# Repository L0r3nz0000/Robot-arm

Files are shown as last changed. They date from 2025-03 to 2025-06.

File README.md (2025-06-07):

# 🤖 Braccio Robotico con Arduino

## 🔧 Introduzione

Questo progetto nasce da un’idea personale, realizzato interamente in autonomia con l’obiettivo di costruire un **braccio robotico a 3 gradi di libertà** utilizzando **stampa 3D** e componenti elettronici a bassissimo costo. Il sistema è pensato per essere controllato in **tempo reale** tramite diverse interfacce.

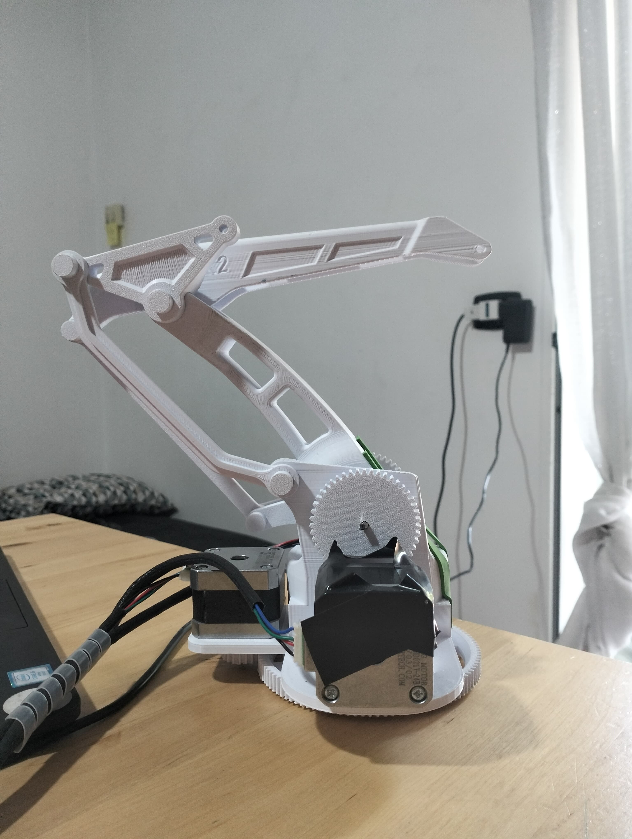
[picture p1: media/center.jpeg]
Braccio Robotico


---

## 🛠️ Struttura Meccanica

- **Gradi di libertà:** 3
- **Base:** rotazione completa a 360° sull'asse verticale  
- **Primo snodo:** movimento fino a 180°  
- **Secondo snodo:** movimento angolare variabile, condizionato dall’orientamento del braccio

**Materiale:** PLA (Polylactic Acid), stampato in 3D  
**Modelli CAD:** scaricati da [Thingiverse](https://www.thingiverse.com/)  
**Trasmissione del moto:** giunti con ingranaggi e riduttori meccanici per aumentare la coppia disponibile

---

## ⚙️ Componenti Elettronici

- **Microcontrollore:** Arduino Uno €20
- **Motori:** 3 × motori stepper NEMA17 €15 - €30
- **Driver motori:** 3 × DRV8825 €3
- **Scheda di controllo:** CNC Shield V3 per Arduino €5
- **Buzzer:** Buzzer passivo elegoo €1.5
- **Alimentazione:** 12V tramite alimentatore esterno

### Totale: ~ €50

---

## 🖥️ Sistema di Controllo e Software

Il braccio è controllabile in **tempo reale** attraverso due modalità principali:

### 1. 🕹️ Controller PlayStation 5

- Acquisizione degli input tramite `pygame`
- Invio comandi seriali diretti ad Arduino

### 2. 🌐 Interfaccia Web (Flask)

- Applicazione web in Python con `Flask`
- Controllo del braccio tramite browser locale

### Architettura Software

**Firmware Arduino**
- Linguaggio: C++
- Nessuna libreria esterna utilizzata

**Client PC**
- Linguaggio: Python
- Librerie principali: `serial` (comunicazione), `pygame` (input controller)

---

## 🧪 Test e Risultati

✅ Il braccio risponde ai comandi con **latenza minima** e **movimenti fluidi**  
✅ La precisione dei motori è molto alta, grazie ai driver che permettono microstep di 1/32 di step e per fare un giro completo dobbiamo fare 64 step, 64*32 = 2048 step per fare un giro completo, quindi otteniamo un'accuratezza di ~0.176 gradi

### Limiti attuali:

- ❌ Assenza di feedback di posizione (encoder/potenziometri)
- ❌ Vincoli meccanici sul terzo snodo per geometria attuale
- ❌ Nessun finecorsa → minor affidabilità in sessioni lunghe

---

## 🚀 Espansioni Future

- ✅ Installazione di finecorsa o sensori di posizione  
- ✅ Aggiunta di ulteriori gradi di libertà (es. **pinza terminale**)  
- ✅ Integrazione di un modulo wireless che permetta di lavorare in modo autonomo (ESP32 o modulo Bluetooth 5.0)  
- ✅ Modalità autonoma programmabile (tramite cinematica inversa)
---

### 📷 Scheda di controllo
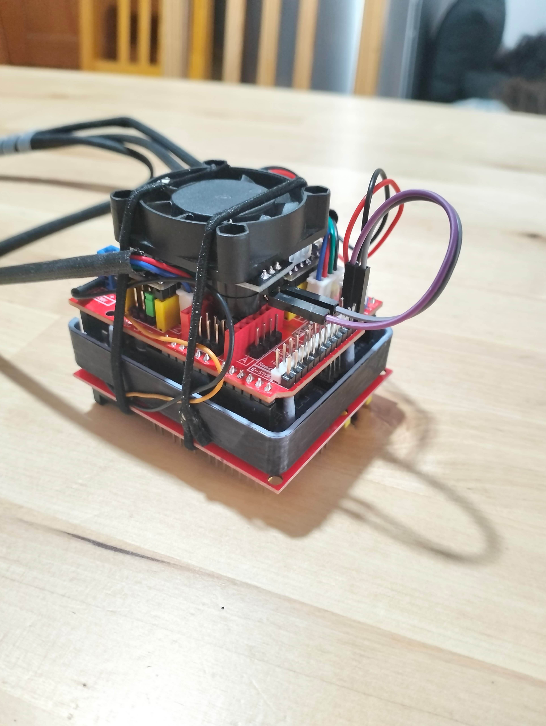
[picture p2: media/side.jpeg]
Foto del braccio


### 🎥 Video dimostrativo (cliccare sull'immagine per aprire)
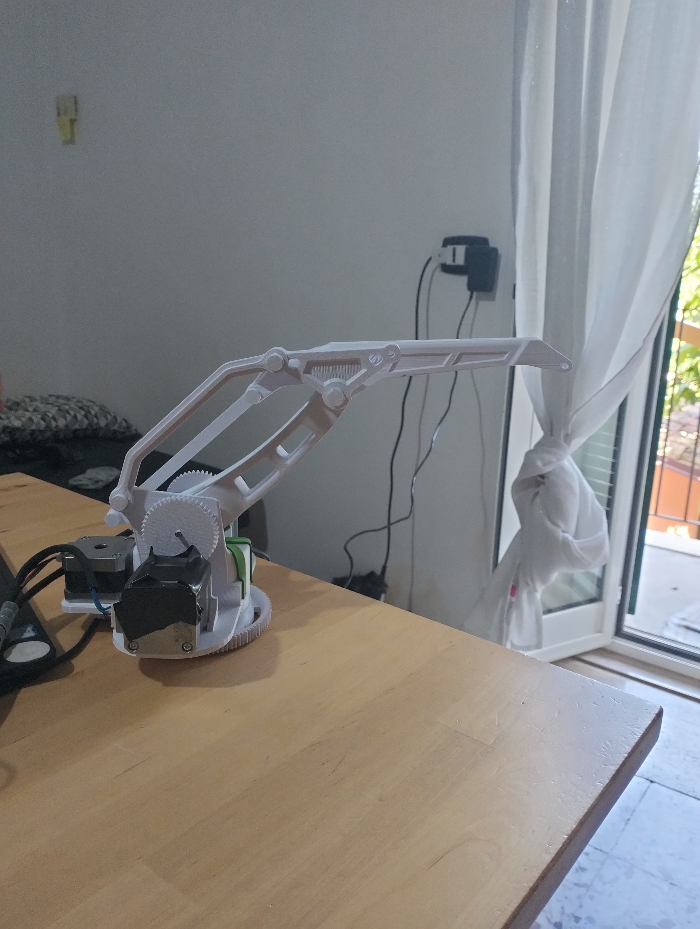
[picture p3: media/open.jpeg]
Guarda il video


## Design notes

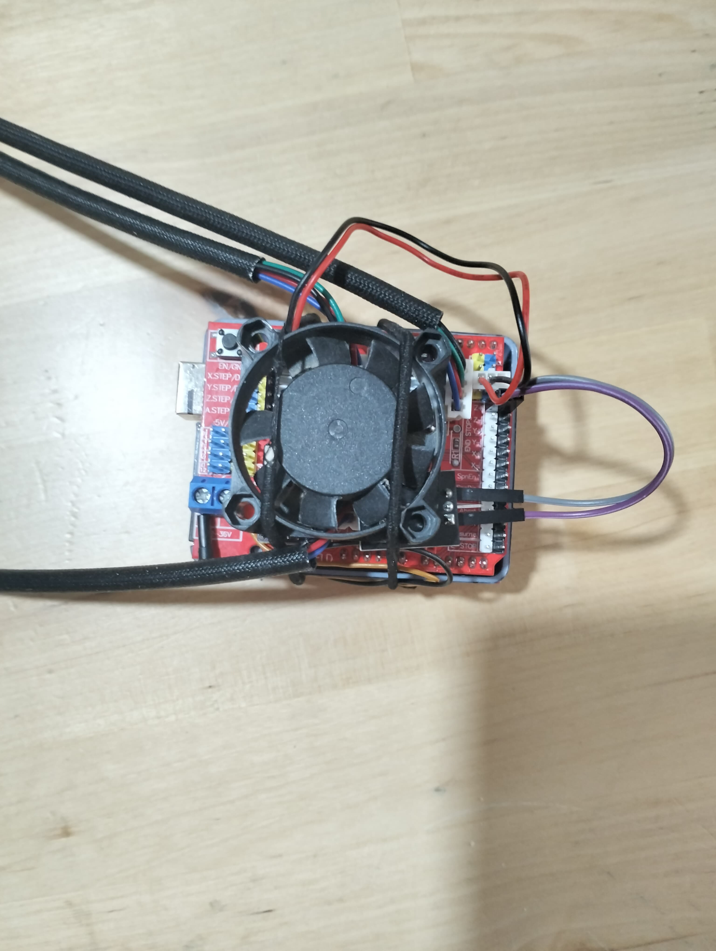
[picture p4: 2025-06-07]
media/up.jpeg

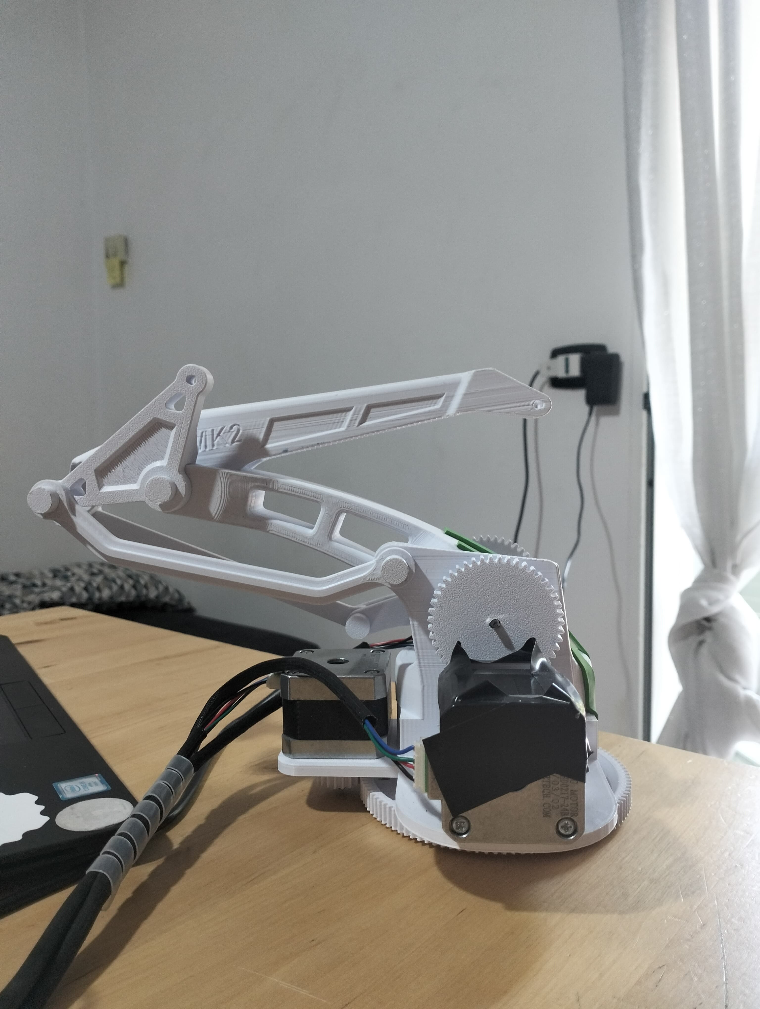
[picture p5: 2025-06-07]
media/closed.jpeg

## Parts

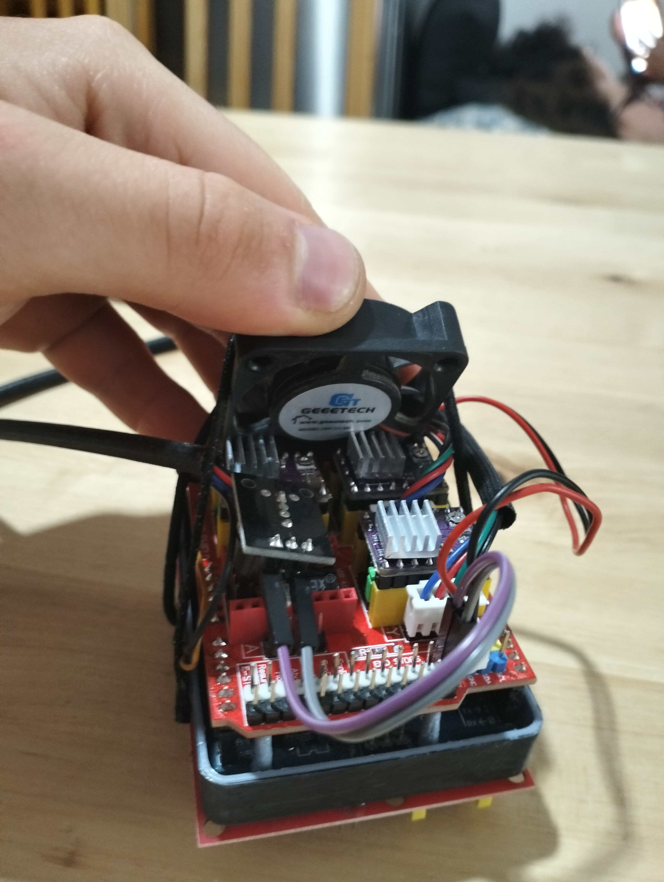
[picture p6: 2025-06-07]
media/internal_components.jpeg

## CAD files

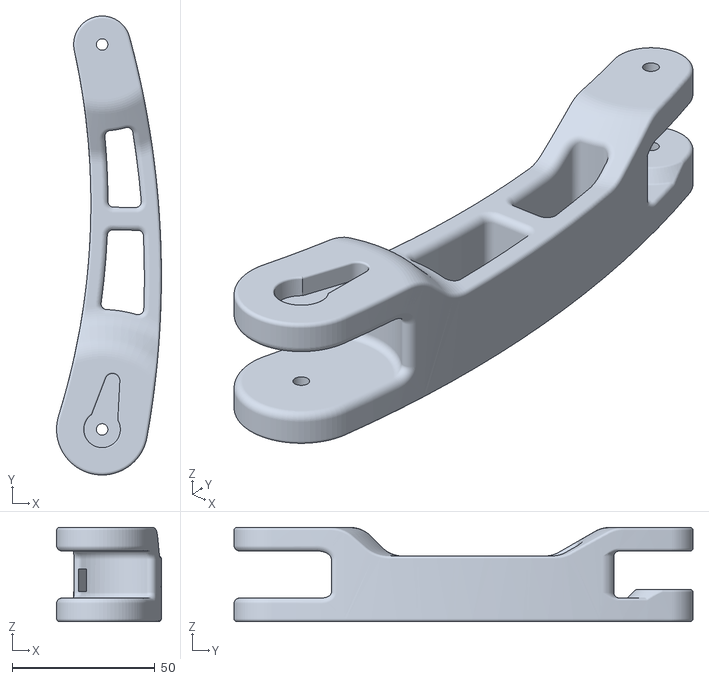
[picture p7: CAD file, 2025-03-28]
3D_models/MK2 Plus/EBAmk2_002_mainarm.STL
36.8 x 161.0 x 33.0

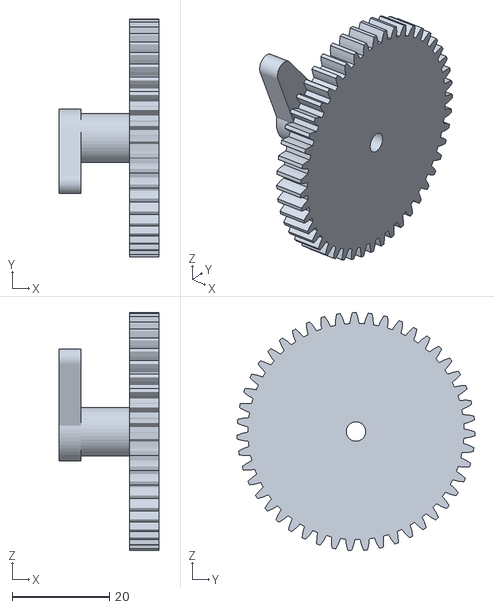
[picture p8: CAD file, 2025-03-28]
3D_models/MK2 Plus/Left_gear.STL
20.5 x 49.0 x 49.0

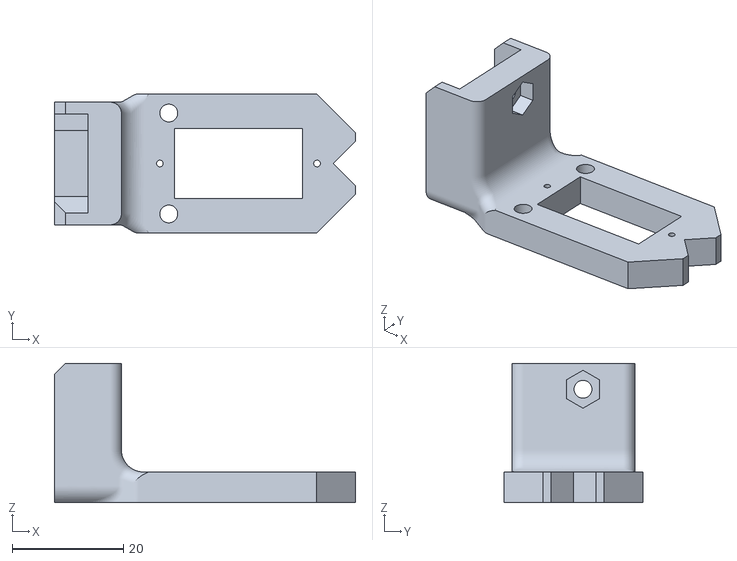
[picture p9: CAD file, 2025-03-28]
3D_models/MK2 Plus/EBAmk2_014_claw_base.STL
54.0 x 25.0 x 25.0

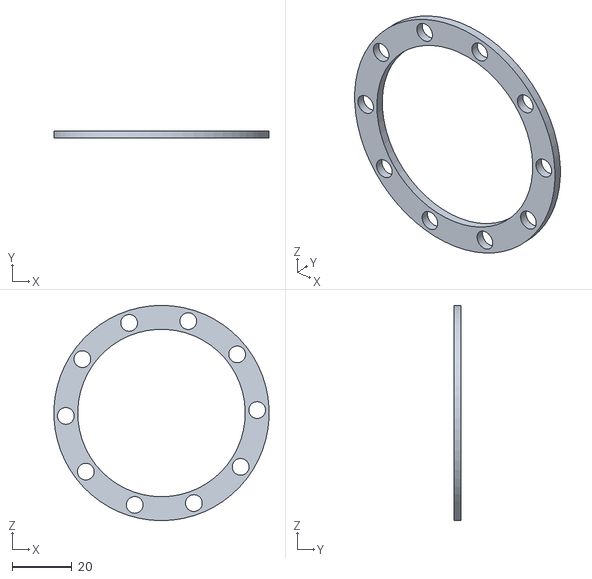
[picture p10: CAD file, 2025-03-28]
3D_models/MK2 Plus/Base_Bearing_Holder.STL
71.9 x 2.50 x 72.0

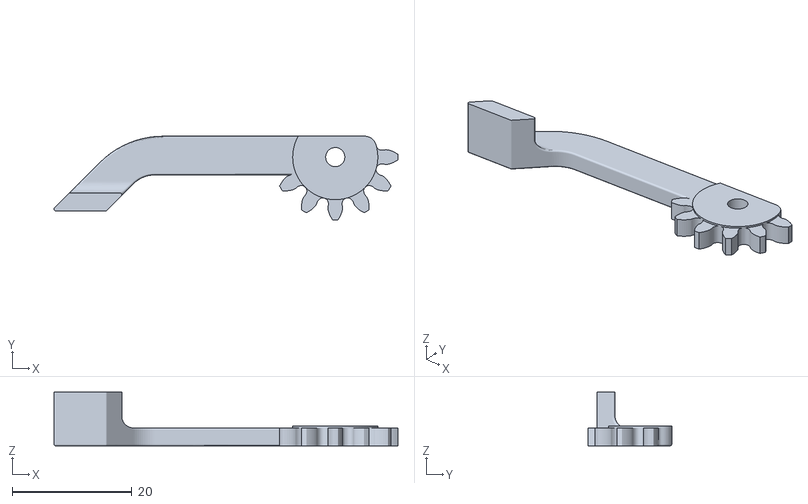
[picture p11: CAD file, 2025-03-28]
3D_models/MK2 Plus/EBAmk2_015_claw_finger_dx.STL
57.6 x 14.0 x 9.00

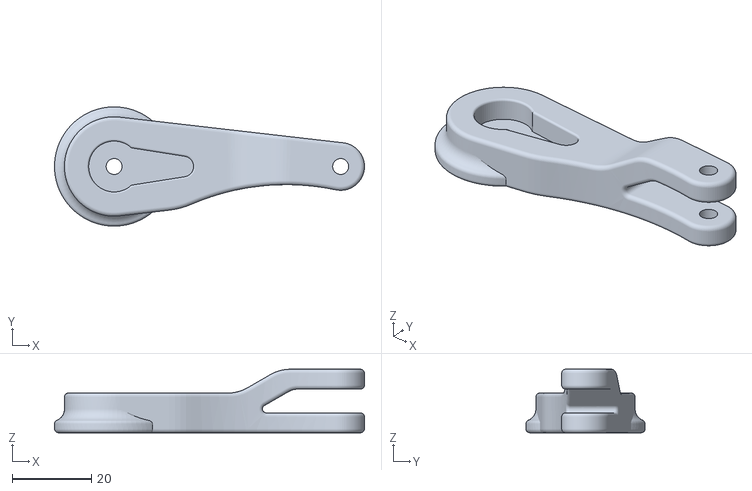
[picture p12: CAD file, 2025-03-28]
3D_models/MK2 Plus/EBAmk2_003_varm.STL
78.0 x 30.0 x 16.0

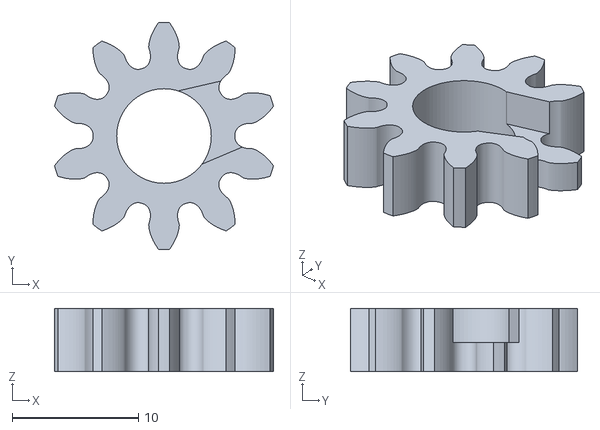
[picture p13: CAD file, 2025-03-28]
3D_models/MK2 Plus/EBAmk2_016_claw_gear_drive.STL
17.4 x 18.0 x 5.00

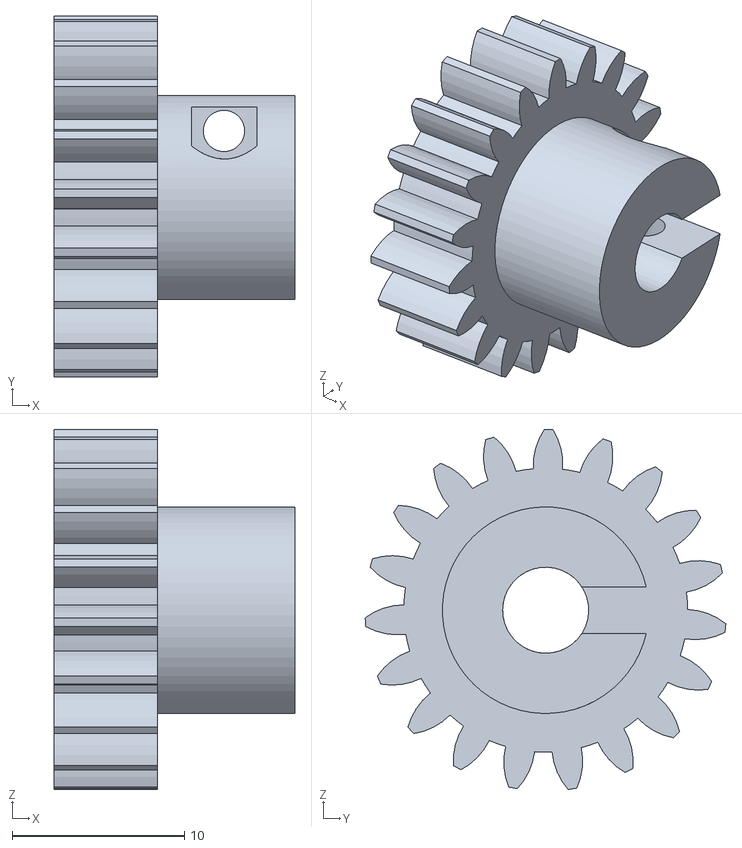
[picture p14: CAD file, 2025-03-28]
3D_models/MK2 Plus/Stepper_Gear.STL
14.0 x 21.0 x 20.9

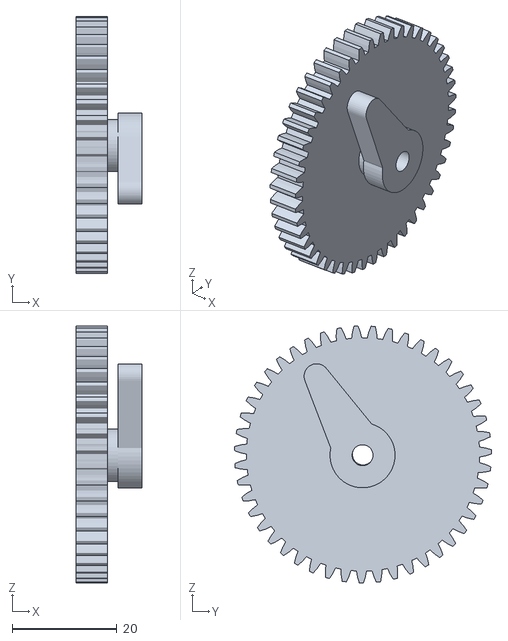
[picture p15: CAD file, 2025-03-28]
3D_models/MK2 Plus/gear1.STL
12.5 x 49.0 x 49.0

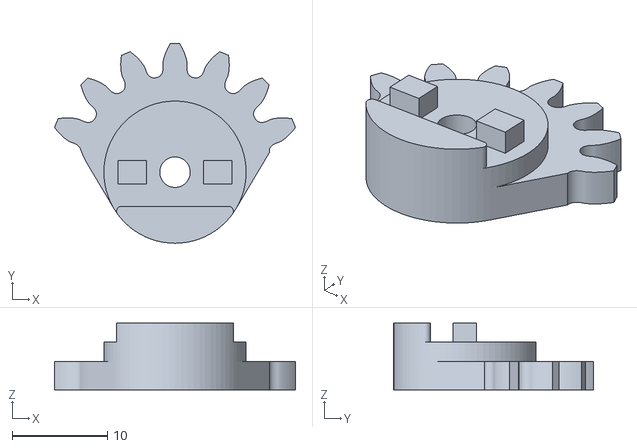
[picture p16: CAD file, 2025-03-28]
3D_models/MK2 Plus/EBAmk2_018_claw_gear_driven.STL
25.3 x 21.0 x 7.00

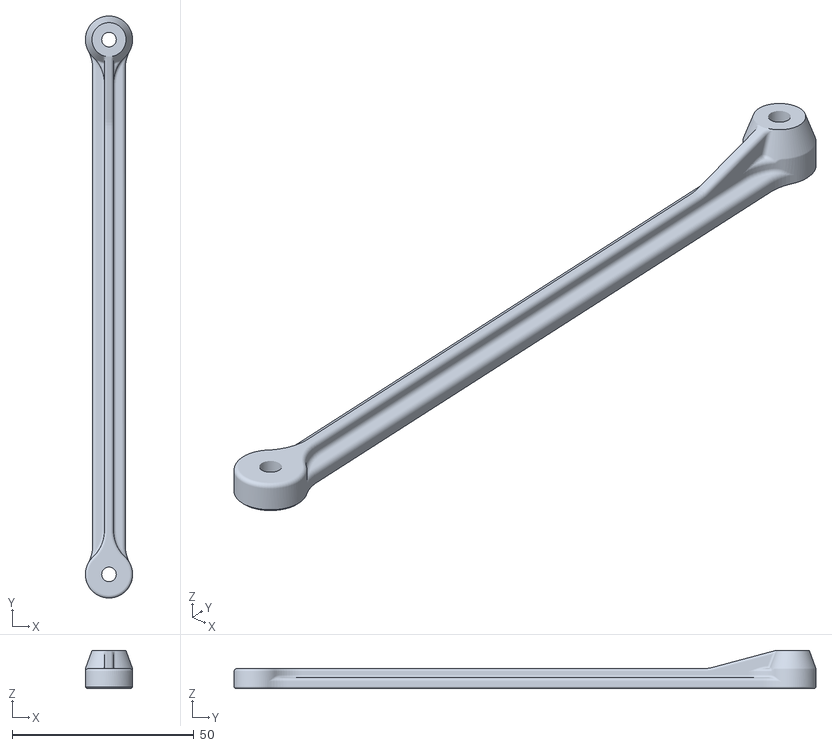
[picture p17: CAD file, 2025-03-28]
3D_models/MK2 Plus/EBAmk2_008_link147_new.STL
13.0 x 160.0 x 10.5

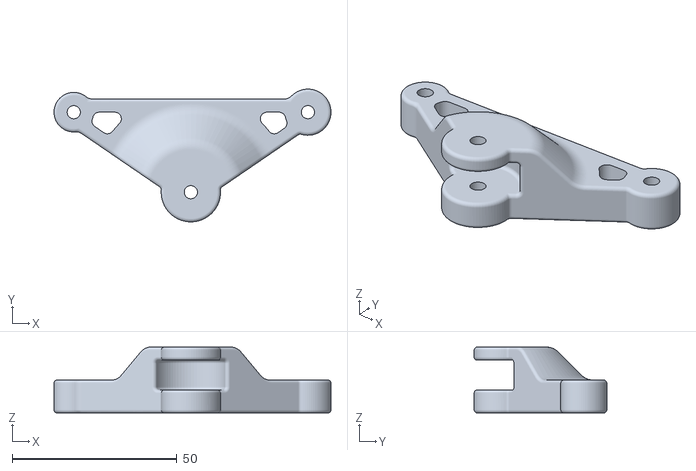
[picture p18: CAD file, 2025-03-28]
3D_models/MK2 Plus/EBAmk2_007_trialink.STL
84.0 x 40.3 x 20.0

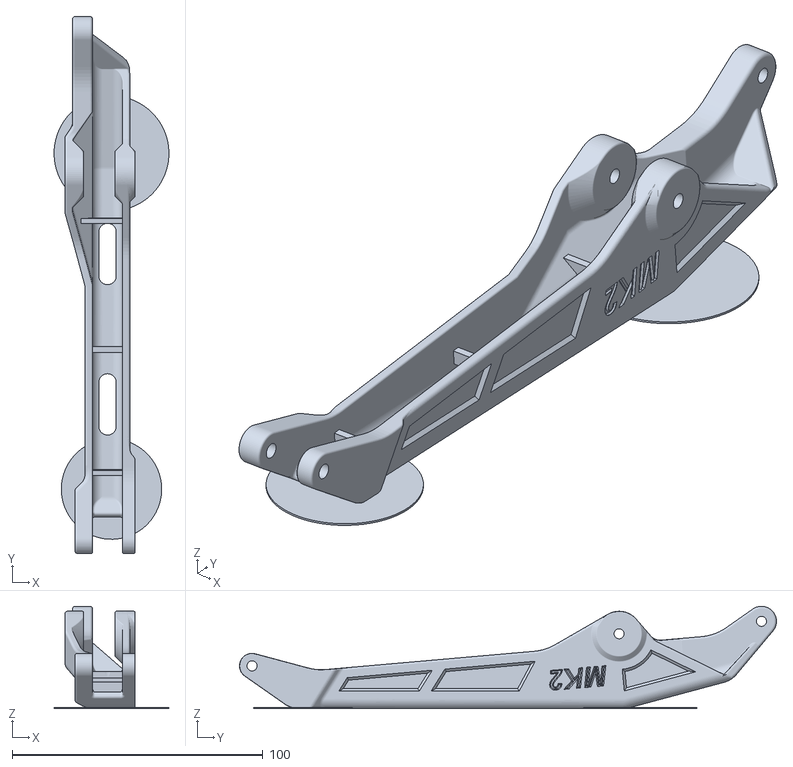
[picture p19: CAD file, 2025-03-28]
3D_models/MK2 Plus/EBAmk2_006_horarm_plate.STL
45.8 x 214.2 x 40.9

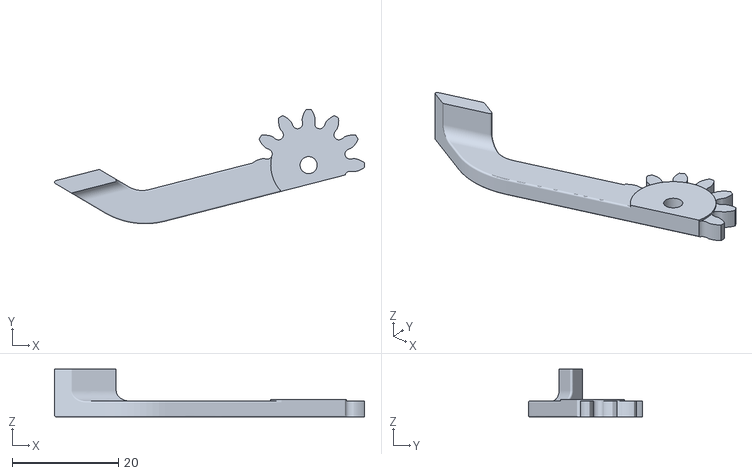
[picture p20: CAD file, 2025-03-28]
3D_models/MK2 Plus/EBAmk2_017_claw_finger_sx.STL
58.3 x 21.5 x 9.00

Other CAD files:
3D_models/MK2 Plus/EBAmk2_004_link135.STL
3D_models/MK2 Plus/Base_Bearing_Ball.STL
3D_models/MK2 Plus/Robot_Base_Low.STL
3D_models/MK2 Plus/EBAmk2_006_horarm__.STL
3D_models/Bolts/M5_Nut.stl
3D_models/Bolts/M5x25_Bolt_D.stl
3D_models/Bolts/M5x65_Bolt_D.stl
3D_models/Bolts/Mount_Camera_Screw.stl
3D_models/MK2 Plus/Base_Arm.STL
3D_models/MK2 Plus/EBAmk2_005_link135angled.STL
3D_models/MK2 Plus/EBAmk2_009_trialinkfront.STL
3D_models/MK2 Plus/Robot_Base_Low_Gear.STL
3D_models/MK2 Plus/finalholder.STL
3D_models/MK2 Plus/gear2.STL
3D_models/MK2 Plus/screw_holder1.STL
3D_models/MK2 Plus/screw_holder2.STL

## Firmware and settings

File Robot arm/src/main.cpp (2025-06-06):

#include <Arduino.h>
#include "stepper.hpp"

#define STEPPER_0_STEP 2
#define STEPPER_0_DIR 5
#define STEPPER_1_STEP 3
#define STEPPER_1_DIR 6
#define STEPPER_2_STEP 4
#define STEPPER_2_DIR 7

#define ENABLE 8
#define BUZZER 11

struct ArmPosition {
  float theta0;  // Base
  float theta1;  // Primo snodo (alla base)
  float theta2;  // Secondo snodo
};

long speed = 300;  // Velocità (step/secondo)

const float L1_size = 13.2, L2_size = 14.6;
const float scale_ratio = 2.5;
const float scale_ratio_rotation = 5.65;

const int theta0_max_extension = 140;
int theta1_max_extension;

bool is_moving = false;

// Angoli dei motori
ArmPosition angles = (ArmPosition) {0, 0, 0};

StepperMotor motors[3] = {
  StepperMotor(STEPPER_0_STEP, STEPPER_0_DIR, scale_ratio),
  StepperMotor(STEPPER_1_STEP, STEPPER_1_DIR, scale_ratio),
  StepperMotor(STEPPER_2_STEP, STEPPER_2_DIR, scale_ratio_rotation)
};

void set_angles(ArmPosition target_angles) {
  if (target_angles.theta0 <= theta0_max_extension) {
    motors[0].setTargetDegrees(target_angles.theta0 * scale_ratio);
    angles.theta0 = target_angles.theta0;
  } else {
    motors[0].setTargetDegrees(theta0_max_extension);
    angles.theta0 = theta0_max_extension;
  }

  if (target_angles.theta1 < target_angles.theta0 ){
    motors[1].setTargetDegrees(-(target_angles.theta0 - target_angles.theta1) * scale_ratio);
  } else {
    motors[1].setTargetDegrees(0);
  }
  
  motors[2].setTargetDegrees(target_angles.theta2 * scale_ratio_rotation);
}

void moveTo(ArmPosition target_angles) {
  set_angles(target_angles);

  while (motors[0].isRunning() || motors[1].isRunning() || motors[2].isRunning()) {
    motors[0].run();
    motors[1].run();
    motors[2].run();
  }
}

void setup() {
  Serial.begin(115200);
  while (!Serial);
  Serial.println("Inizializzazione...");
  Serial.readStringUntil('\n');
  Serial.setTimeout(500);

  // Inizializza i motori
  for (int i = 0; i < 2; i++) {
    motors[i].setMinSpeed(5);
    motors[i].setMaxSpeed(speed);
    motors[i].setAcceleration(8000);
  }
  motors[2].setMinSpeed(5);
  motors[2].setMaxSpeed(1800);
  motors[2].setAcceleration(12000);


  // Inizializza il pin di abilitazione
  pinMode(ENABLE, OUTPUT);
  // Inizializza il pin del buzzer
  pinMode(BUZZER, OUTPUT);

  // digitalWrite(ENABLE, HIGH); // Disabilita i driver

  // for (int i = 0; i < 3; i++) {
  //   delay(50);
  //   digitalWrite(BUZZER, HIGH);
  //   delay(100);
  //   digitalWrite(BUZZER, LOW);
  // }

  // delay(4000);
  // digitalWrite(BUZZER, HIGH);
  // delay(600);
  // digitalWrite(BUZZER, LOW);

  digitalWrite(ENABLE, LOW); // Abilita i driver
  delay(300);

  // Inizializza la posizione iniziale
  angles.theta0 = 0;
  angles.theta1 = 0;
  angles.theta2 = 0;

  moveTo({45, 63, 0});
  moveTo({0, 0, 0});
}

void loop() {
  if (Serial.available()) {
    Serial.readStringUntil('\t');  // inizio comunicazione
    float t0 = Serial.readStringUntil(' ').toInt();
    float t1 = Serial.readStringUntil(' ').toInt();
    float t2 = Serial.readStringUntil('\n').toInt();
    
    if (t0 != 0) {
      motors[0].runContinuously(t0);
    } else {
      motors[0].stop();
    }

    if (t1 != 0) {
      motors[1].runContinuously(t1);
    } else {
      motors[1].stop();
    }

    if (t2 != 0) {
      motors[2].runContinuously(t2);
    } else {
      motors[2].stop();
    }

    // Nuovo comando ricevuto, aggiorna target e inizia il movimento
    is_moving = true;
    Serial.print("theta0: ");
    Serial.print(motors[0].getPositionDegree());
    Serial.print(" theta1: ");
    Serial.print(motors[1].getPositionDegree());
    Serial.print(" theta2: ");
    Serial.println(motors[2].getPositionDegree());
  }

  // Esegui il movimento se attivo
  if (is_moving) {
    motors[0].run();
    motors[1].run();
    motors[2].run();

    if (!motors[0].isRunning() && !motors[1].isRunning() && !motors[2].isRunning()) {
      is_moving = false; // movimento completato
    }
  }
}

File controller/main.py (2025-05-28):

import serial
import pygame
import time

pygame.init()
pygame.joystick.init()

# Inizializza il primo joystick disponibile
if pygame.joystick.get_count() == 0:
  print("Nessun joystick trovato.")
  exit()

joystick = pygame.joystick.Joystick(0)
joystick.init()

print(f"Joystick connesso: {joystick.get_name()}")
print(f"Numero di assi disponibili: {joystick.get_numaxes()}")

PORT = '/dev/ttyACM0' # porta seriale della scheda
BAUDRATE = 115200 # velocità di comunicazione

try:
  ser = serial.Serial(PORT, BAUDRATE)
except:
  print("Impossibile connettersi al robot")
  exit(1)

try:
  while True:
    pygame.event.pump()  # Necessario per aggiornare gli input

    left_axis_rotation = round(-joystick.get_axis(0), 1) * 4
    left_axis = round(-joystick.get_axis(1), 1) * 4
    right_axis = round(-joystick.get_axis(4), 1)
    
    if left_axis != 0 or right_axis != 0 or left_axis_rotation != 0:
      x += left_axis
      x = min(max(x, 0), 135)
      y += right_axis
      y = min(max(y, 0), x)
      z += left_axis_rotation
      ser.write(f"{int(x+y+z)} {x:.2f} {y:.2f} {z:.2f}\n".encode())
      print(f"Invio: {int(x+y+z)}\t{x:.2f}\t{y:.2f}\t{z:.2f}")
    
    time.sleep(0.1)
except KeyboardInterrupt:
  print("Uscita dallo script.")

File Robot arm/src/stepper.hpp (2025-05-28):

#include <Arduino.h>

class StepperMotor {
  private:
    int step_pin, dir_pin;

    // Configurazione dei driver
    float angle_for_step = 1.8;  // 1.8° per step con i nema 17
    int microsteps = 16;  // 1=full step, 2=half step, 4=quarter step...
    float scale_ratio = 1;
    float steps_per_degree;
    unsigned int maxSpeed = 1000 * microsteps;   // Max speed in steps/sec
    unsigned int minSpeed = 100 * microsteps;    // Min speed (starting speed)
    unsigned int accel = 200;       // Acceleration in steps/sec^2

    int positionStep = 0;
    float positionDegree = 0;
    int targetSteps = 0;
    unsigned long lastStepTime = 0;

    bool continuousMode = false;

    float currentSpeed = 0;         // In steps/sec
    float stepInterval = 0;         // In ms

    int direction = 1;              // 1: avanti, -1: indietro
    bool running = false;

    void step() {
      digitalWrite(dir_pin, direction == 1 ? HIGH : LOW);
      digitalWrite(step_pin, HIGH);
      delayMicroseconds(10);
      digitalWrite(step_pin, LOW);
      delayMicroseconds(10);

      positionStep += direction;
      positionDegree += direction * (1.0 / steps_per_degree);
    }

    void computeSpeed() {
      int stepsRemaining = abs(targetSteps - positionStep);
      float targetSpeed = maxSpeed;

      // Accelerazione
      float accelSteps = (float)(currentSpeed * currentSpeed) / (2.0 * accel);
      if (stepsRemaining < accelSteps * 2) {
        // Decelera
        targetSpeed = sqrt(2.0 * accel * (stepsRemaining / 2.0));
        if (targetSpeed < minSpeed) targetSpeed = minSpeed;
      } else if (currentSpeed < maxSpeed) {
        // Accelera
        targetSpeed = currentSpeed + accel * ((millis() - lastStepTime) / 1000.0);
        if (targetSpeed > maxSpeed) targetSpeed = maxSpeed;
      }

      currentSpeed = targetSpeed;
      stepInterval = 1000.0 / currentSpeed;
    }

  public:
    StepperMotor(int step_pin, int dir_pin, float scale_ratio = 1) {
      this->step_pin = step_pin;
      this->dir_pin = dir_pin;
      this->scale_ratio = scale_ratio;
      steps_per_degree = (microsteps * scale_ratio) / angle_for_step;

      pinMode(step_pin, OUTPUT);
      pinMode(dir_pin, OUTPUT);
      digitalWrite(step_pin, LOW);
      digitalWrite(dir_pin, LOW);
    }

    void setMaxSpeed(unsigned int speed) { if (speed > 0) maxSpeed = speed * microsteps; }
    void setMinSpeed(unsigned int speed) { if (speed > 0) minSpeed = speed * microsteps; }
    void setAcceleration(unsigned int a) { if (a > 0) accel = a; }

    void setTargetDegrees(float angleDeg) {
      int steps = lround(angleDeg * steps_per_degree);
      targetSteps = steps;
      direction = (targetSteps > positionStep) ? 1 : -1;
      running = true;
      currentSpeed = minSpeed;
      stepInterval = 1000.0 / currentSpeed;
      lastStepTime = millis();
    }

    void runContinuously(int dir) {
      direction = (dir >= 0) ? 1 : -1;
      continuousMode = true;
      running = true;
      currentSpeed = minSpeed;
      stepInterval = 1000.0 / currentSpeed;
      lastStepTime = millis();
    }

    void run() {
      if (!running) return;

      if ((millis() - lastStepTime) >= stepInterval) {
        if (!continuousMode && positionStep == targetSteps) {
          running = false;
          return;
        }

        step();
        computeSpeed();
        lastStepTime = millis();
      }
    }

    void stop() {
      running = false;
      continuousMode = false;
      targetSteps = positionStep;
    }

    bool isRunning() { return running; }
    bool isContinuous() { return continuousMode; }
    int getPositionStep() { return positionStep; }
    float getPositionDegree() { return positionDegree; }
};

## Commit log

2025-03-20 added smaller model for nema 17 motors
    [01_Stand_(nema-17).stl]
2025-05-28 odio la meccanica
